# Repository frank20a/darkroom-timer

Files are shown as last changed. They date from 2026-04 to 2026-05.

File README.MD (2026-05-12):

# Darkroom f-stop timer

## Known issues:
- [X] Fix EPD power pin connected to 3.3V instead of 3V3 in KiCad schematic
- [ ] Fix SD card support (or remove it)
- [ ] Fix relays not working on PCB
- [ ] Fix issue with power supply voltage drop
    1. Test with a different power supply
    2. Add voltage measurement feedback to the microcontroller to monitor voltage levels

## Additions for future revisions:
- [ ] Add/Implement the following settings on the menu:
    - [ ] Ramp speed for light output changes
    - [ ] Save & Load templates
- [ ] Move EPD to a separate SPI bus to free up the main SPI bus for other peripherals
- [ ] Move EPD processing to a separate thread to improve responsiveness of the main application
- [ ] Add a safelight switch that bypasses everything
- [ ] Foot pedal support
- [ ] Add sensor support for light and contrast metering
- [ ] Add sensor support for color balancing

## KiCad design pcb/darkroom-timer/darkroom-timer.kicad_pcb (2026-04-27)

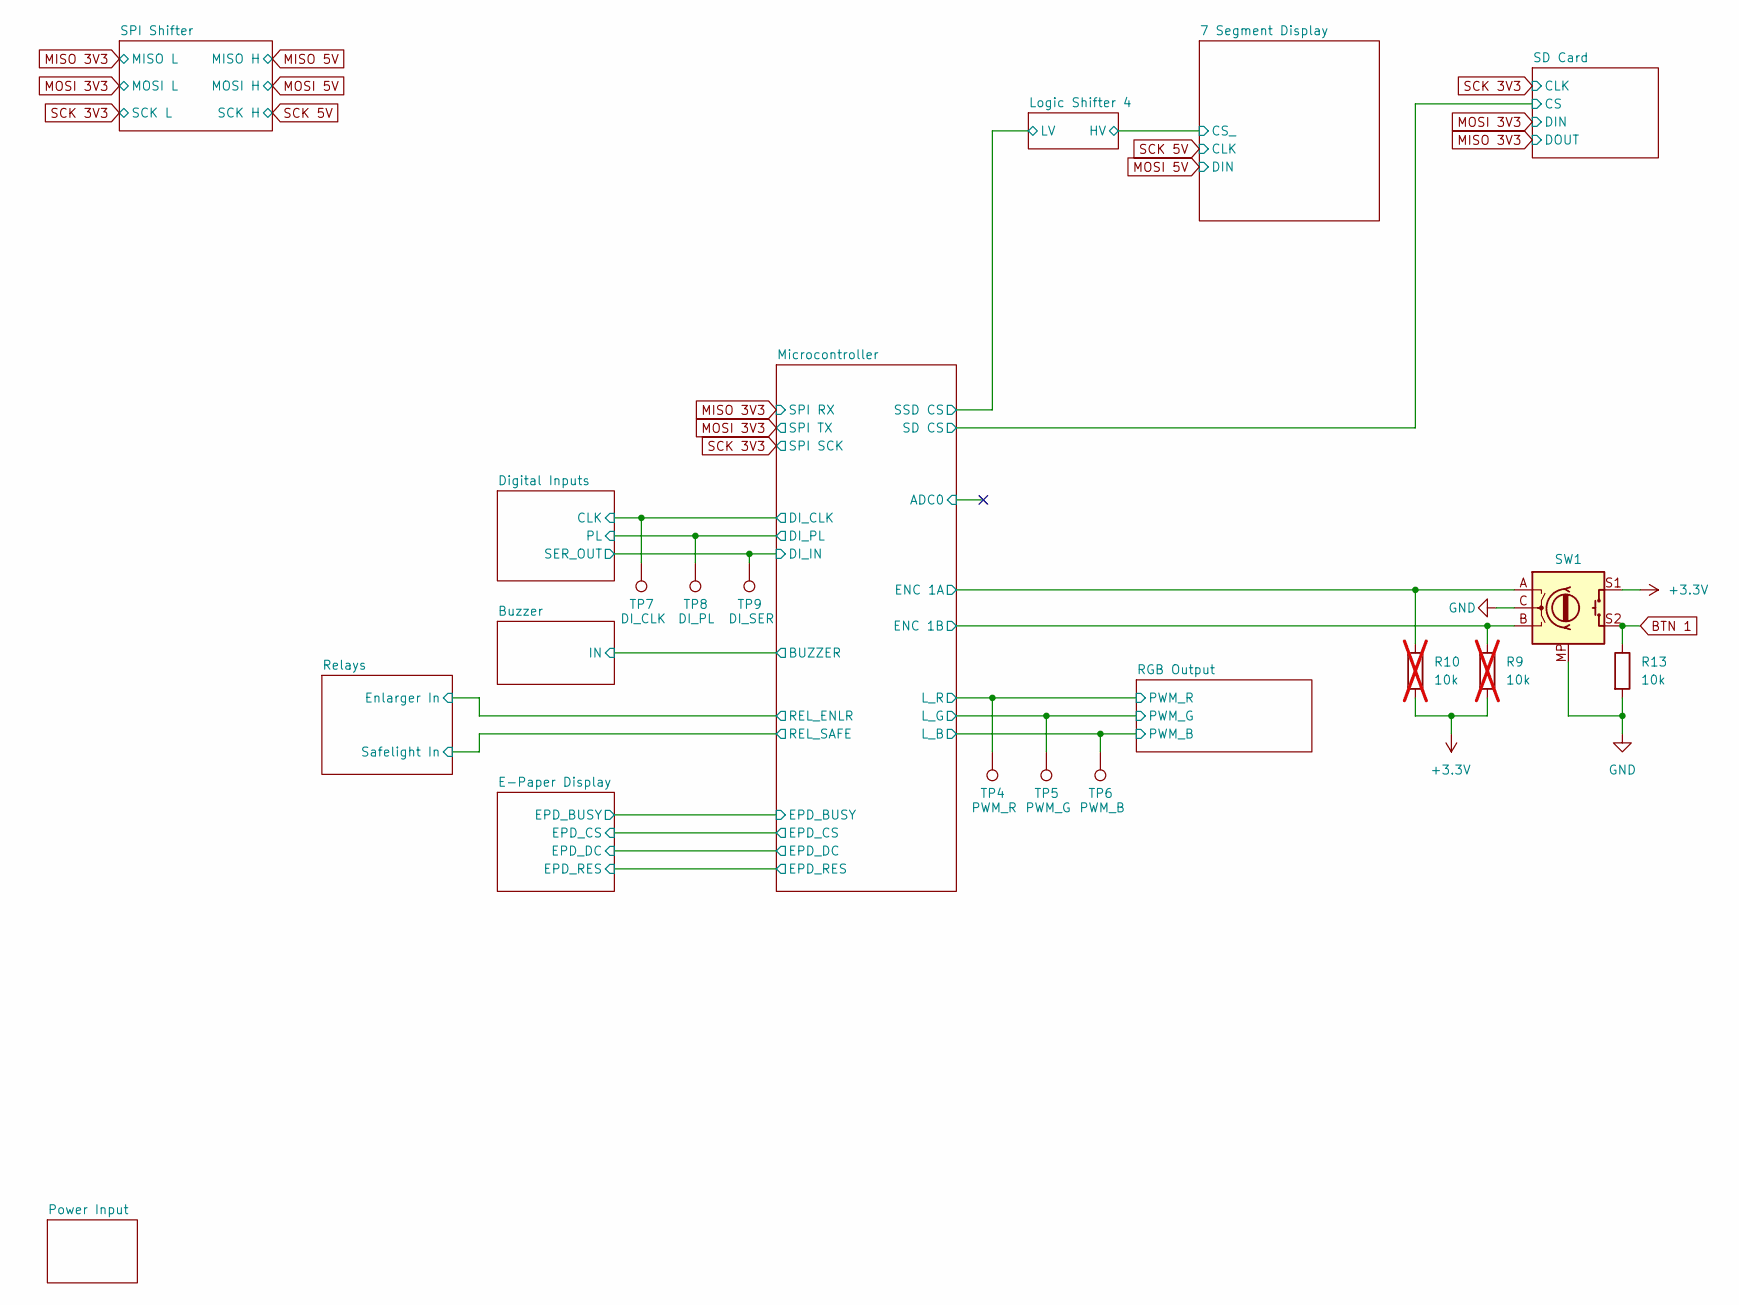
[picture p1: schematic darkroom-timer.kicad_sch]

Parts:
R9, R10: 10k; R_0805_2012Metric; not fitted
R13: 10k; R_0805_2012Metric
SW1: RotaryEncoder_Switch_MP; RotaryEncoder_Alps_EC11E-Switch_Vertical_3D
TP4: PWM_R; TestPoint_Pad_D1.5mm
TP5: PWM_G; TestPoint_Pad_D1.5mm
TP6: PWM_B; TestPoint_Pad_D1.5mm
TP7: DI_CLK; TestPoint_Pad_D1.5mm
TP8: DI_PL; TestPoint_Pad_D1.5mm
TP9: DI_SER; TestPoint_Pad_D1.5mm

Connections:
+3.3V: R9.2, R10.2, SW1.S1; also elsewhere on the board
/Digital Inputs/CLK: TP7.1; also elsewhere on the board
/Digital Inputs/PL: TP8.1; also elsewhere on the board
/Digital Inputs/SER_OUT: TP9.1; also elsewhere on the board
/Microcontroller/ENC 1A: R10.1, SW1.A; also elsewhere on the board
/Microcontroller/ENC 1B: R9.1, SW1.B; also elsewhere on the board
/Microcontroller/L_B: TP6.1; also elsewhere on the board
/Microcontroller/L_G: TP5.1; also elsewhere on the board
/Microcontroller/L_R: TP4.1; also elsewhere on the board
BTN 1: R13.1, SW1.S2; also elsewhere on the board
Earth: R13.2, SW1.C, SW1.MP; also elsewhere on the board

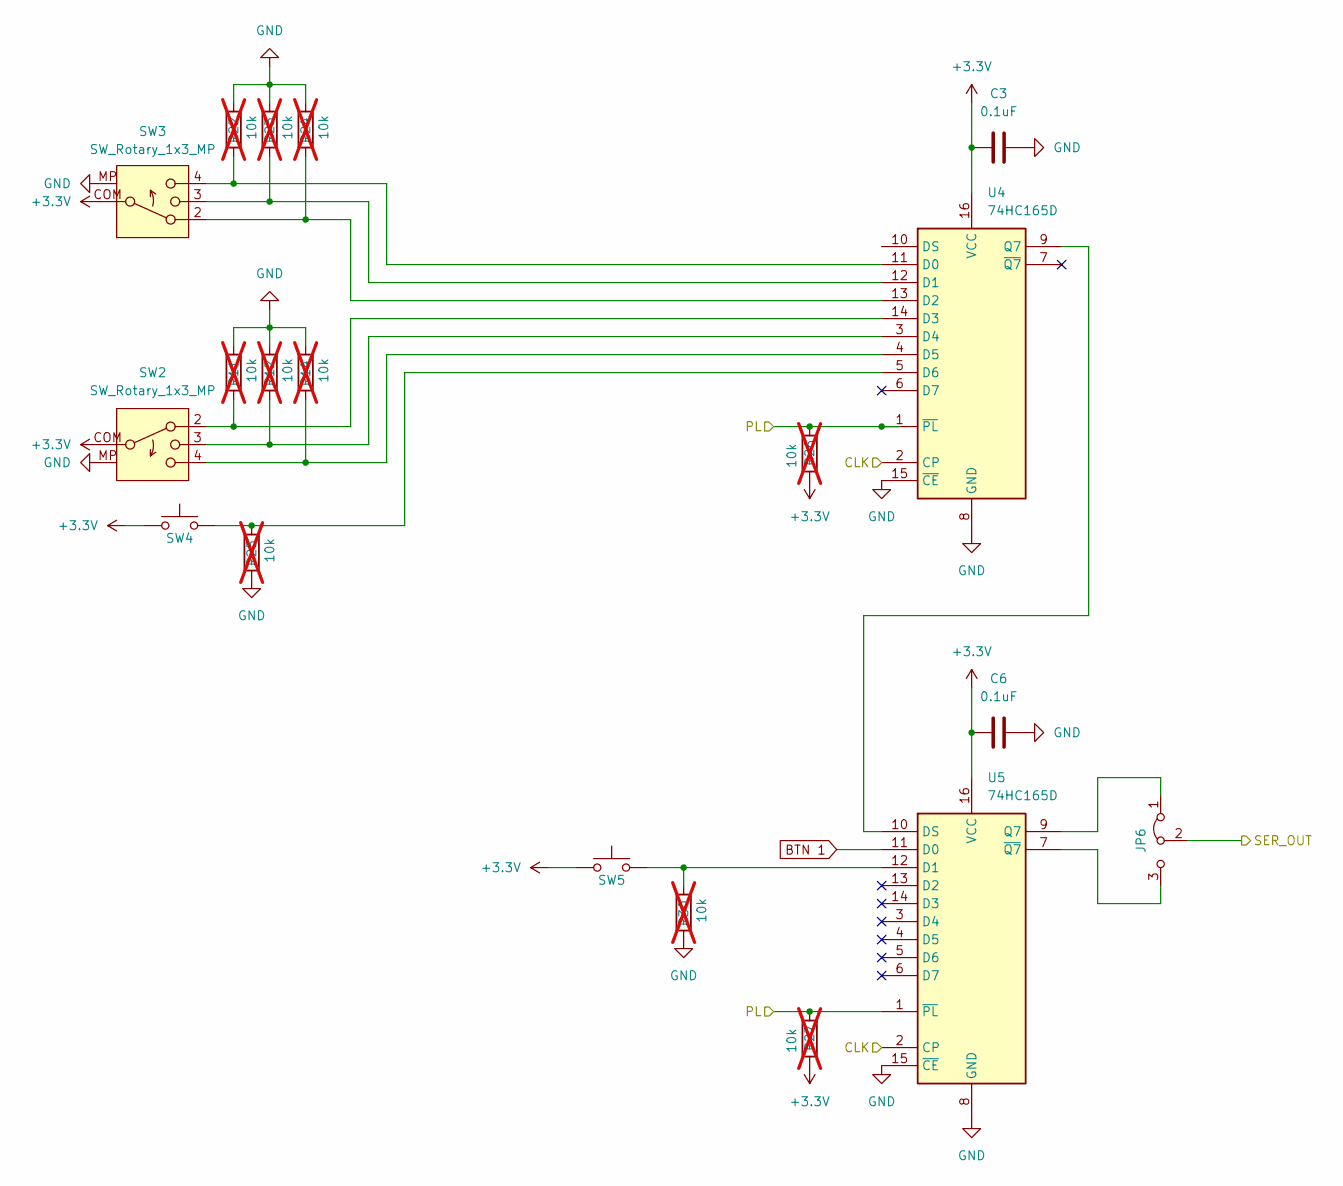
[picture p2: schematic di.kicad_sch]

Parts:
C3, C6: 0.1uF; C_0805_2012Metric
JP6: SolderJumper-3_P1.3mm_Bridged12_Pad1.0x1.5mm
R11, R12, R14, R22, R23, R24, R25, R26, R27, R30: 10k; R_0805_2012Metric; not fitted
SW2, SW3: SW_Rotary_1x3_MP; SR17A-007
SW4: Start Switch; SolderWire-0.25sqmm_1x02_P4.5mm_D0.65mm_OD2mm
SW5: Start Switch; SW_PUSH_6mm_H13mm
U4, U5: 74HC165D; SO-16_3.9x9.9mm_P1.27mm

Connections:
+3.3V: C3.1, C6.1, R26.1, R27.1, SW2.COM, SW3.COM, SW4.1, SW5.1, U4.16 (VCC), U5.16 (VCC); also elsewhere on the board
/Digital Inputs/CLK: U4.2 (CP), U5.2 (CP); also elsewhere on the board
/Digital Inputs/PL: R26.2, R27.2, U4.1 (~PL), U5.1 (~PL); also elsewhere on the board
/Digital Inputs/SER_OUT: JP6.2 (C); also elsewhere on the board
BTN 1: U5.11 (D0); also elsewhere on the board
Earth: C3.2, C6.2, R11.1, R12.1, R14.1, R22.1, R23.1, R24.1, R25.2, R30.2, SW2.MP, SW3.MP, U4.8 (GND), U4.15 (~CE), U5.8 (GND), U5.15 (~CE); also elsewhere on the board
unnamed: JP6.1 (A), U5.9 (Q7)
unnamed: JP6.3 (B), U5.7 (~Q7)
unnamed: R22.2, SW3.4, U4.11 (D0)
unnamed: R23.2, SW3.3, U4.12 (D1)
unnamed: R24.2, SW3.2, U4.13 (D2)
unnamed: R11.2, SW2.2, U4.14 (D3)
unnamed: R12.2, SW2.3, U4.3 (D4)
unnamed: R14.2, SW2.4, U4.4 (D5)
unnamed: R25.1, SW4.2, U4.5 (D6)
unnamed: U4.9 (Q7), U5.10 (DS)
unnamed: R30.1, SW5.2, U5.12 (D1)

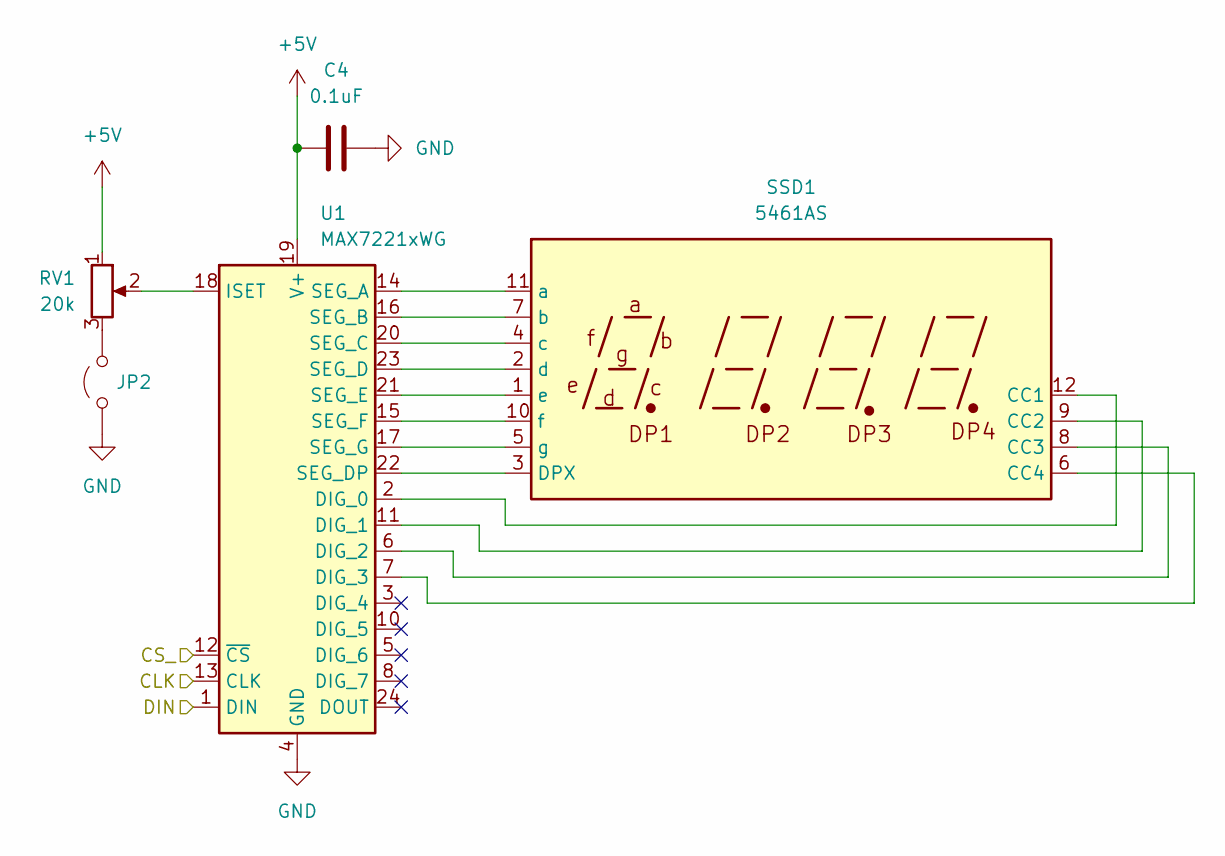
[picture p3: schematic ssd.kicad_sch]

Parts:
C4: 0.1uF; C_0805_2012Metric
JP2: SolderJumper-2_P1.3mm_Open_Pad1.0x1.5mm
RV1: 20k; RKT6V
SSD1: 5461AS; CA56-12EWA
U1: MAX7221xWG; SOIC-24W_7.5x15.4mm_P1.27mm

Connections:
+5V: C4.1, RV1.1, U1.19 (V+); also elsewhere on the board
/7 Segment Display/CS_: U1.12 (~CS); also elsewhere on the board
Earth: C4.2, JP2.1 (A), U1.4 (GND), U1.9 (GND); also elsewhere on the board
MOSI 5V: U1.1 (DIN); also elsewhere on the board
unnamed: JP2.2 (B), RV1.3
unnamed: SSD1.12 (CC1), U1.2 (DIG_0)
unnamed: SSD1.9 (CC2), U1.11 (DIG_1)
unnamed: SSD1.8 (CC3), U1.6 (DIG_2)
unnamed: SSD1.6 (CC4), U1.7 (DIG_3)
unnamed: SSD1.3 (DPX), U1.22 (SEG_DP)
unnamed: SSD1.11 (a), U1.14 (SEG_A)
unnamed: SSD1.7 (b), U1.16 (SEG_B)
unnamed: SSD1.4 (c), U1.20 (SEG_C)
unnamed: SSD1.2 (d), U1.23 (SEG_D)
unnamed: SSD1.1 (e), U1.21 (SEG_E)
unnamed: SSD1.10 (f), U1.15 (SEG_F)
unnamed: SSD1.5 (g), U1.17 (SEG_G)
unnamed: RV1.2, U1.18 (ISET)
SCK 5V: U1.13 (CLK); also elsewhere on the board

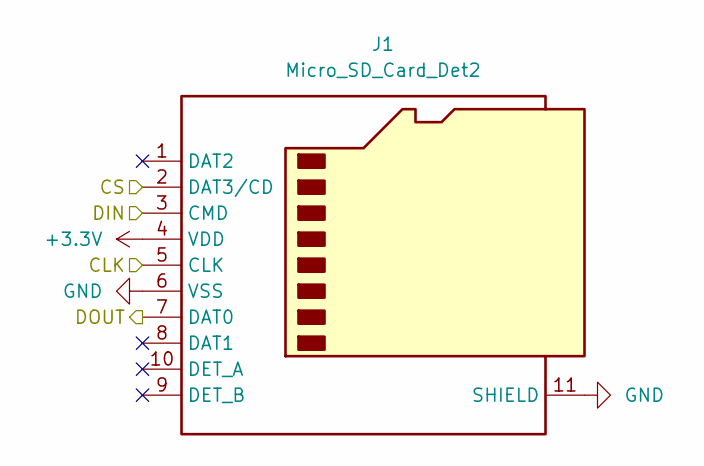
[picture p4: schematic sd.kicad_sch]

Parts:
J1: Micro_SD_Card_Det2; microSD_HC_Hirose_DM3AT-SF-PEJM5

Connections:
+3.3V: J1.4 (VDD); also elsewhere on the board
/Microcontroller/SD CS: J1.2 (DAT3/CD); also elsewhere on the board
Earth: J1.6 (VSS), J1.11 (SHIELD); also elsewhere on the board
MISO 3V3: J1.7 (DAT0); also elsewhere on the board
MOSI 3V3: J1.3 (CMD); also elsewhere on the board
SCK 3V3: J1.5 (CLK); also elsewhere on the board

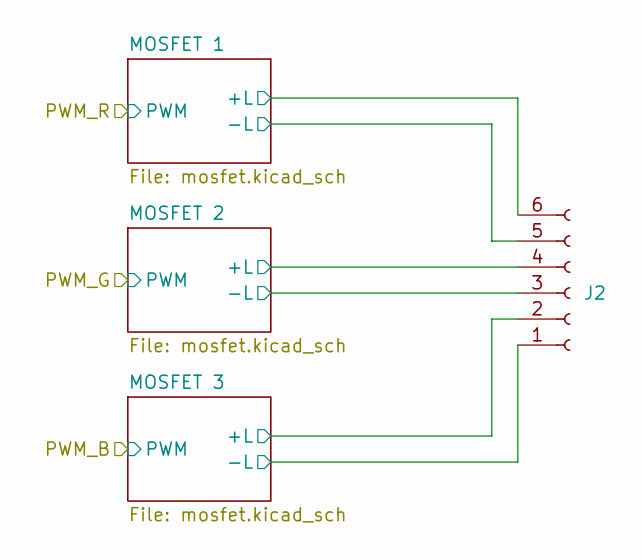
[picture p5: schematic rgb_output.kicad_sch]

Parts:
J2: Conn_01x06_Socket; PhoenixContact_MC_1,5_6-G-3.81_1x06_P3.81mm_Horizontal

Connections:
+24V: J2.2, J2.4, J2.6; also elsewhere on the board
/RGB Output/MOSFET 1/PWR_NEG: J2.5; also elsewhere on the board
/RGB Output/MOSFET 2/PWR_NEG: J2.3; also elsewhere on the board
/RGB Output/MOSFET 3/PWR_NEG: J2.1; also elsewhere on the board

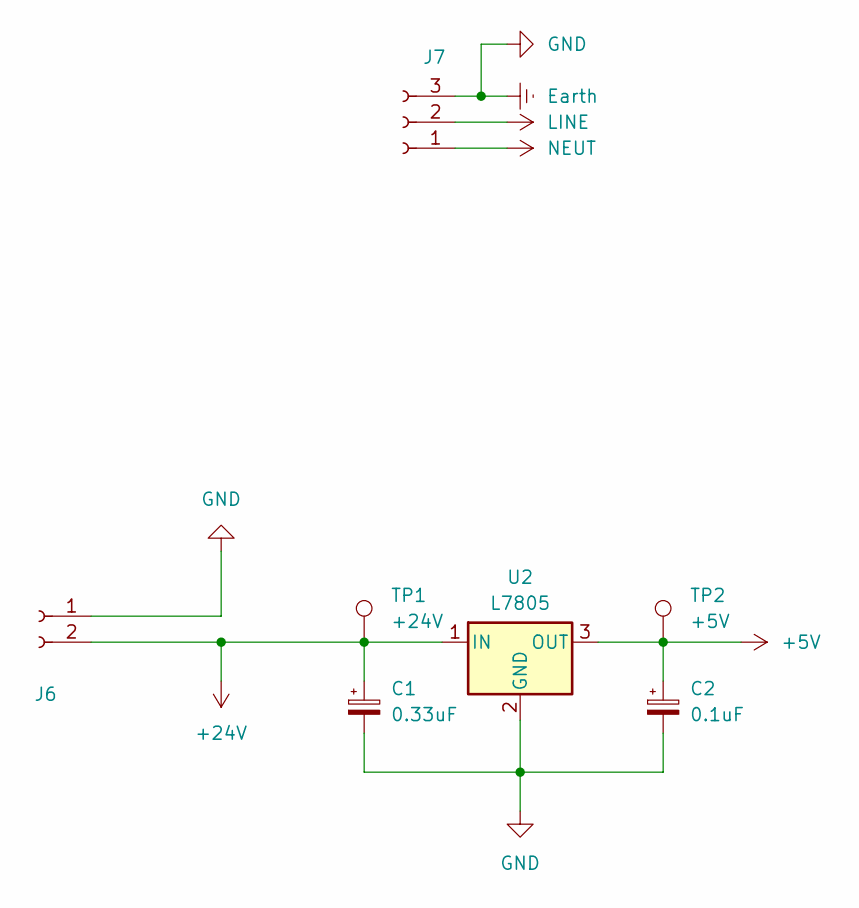
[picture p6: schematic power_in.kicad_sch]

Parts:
C1: 0.33uF; C_Radial_D4.0mm_H7.0mm_P1.50mm
C2: 0.1uF; C_Radial_D4.0mm_H7.0mm_P1.50mm
J6: Conn_01x02_Socket; PhoenixContact_MC_1,5_2-G-3.81_1x02_P3.81mm_Horizontal
J7: Conn_01x03_Socket; TerminalBlock_Phoenix_MKDS-1,5-3_1x03_P5.00mm_Horizontal
TP1: +24V; TestPoint_Pad_D1.5mm
TP2: +5V; TestPoint_Pad_D1.5mm
U2: L7805; TO-220-3_Vertical

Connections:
+5V: C2.1, TP2.1, U2.3 (OUT); also elsewhere on the board
+24V: C1.1, J6.2, TP1.1, U2.1 (IN); also elsewhere on the board
Earth: C1.2, C2.2, J6.1, J7.3, U2.2 (GND); also elsewhere on the board
LINE: J7.2; also elsewhere on the board
NEUT: J7.1; also elsewhere on the board

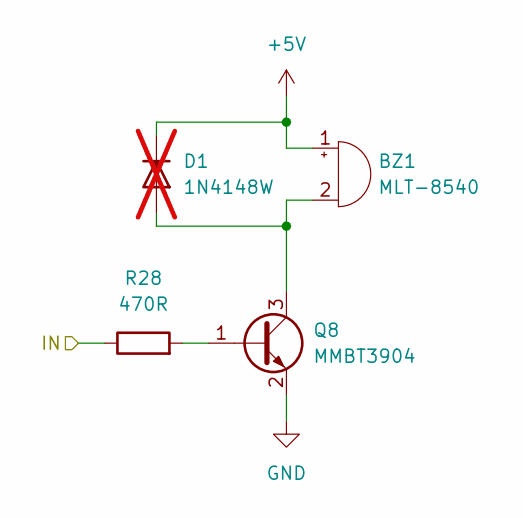
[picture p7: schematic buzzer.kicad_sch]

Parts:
BZ1: MLT-8540; Buzzer_MLT_8540
D1: 1N4148W; D_SOD-123; not fitted
Q8: MMBT3904; TSOT-23_HandSoldering
R28: 470R; R_0805_2012Metric

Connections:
+5V: BZ1.1 (+), D1.1 (K); also elsewhere on the board
/Buzzer/IN: R28.1; also elsewhere on the board
Earth: Q8.2 (E); also elsewhere on the board
unnamed: BZ1.2 (-), D1.2 (A), Q8.3 (C)
unnamed: Q8.1 (B), R28.2

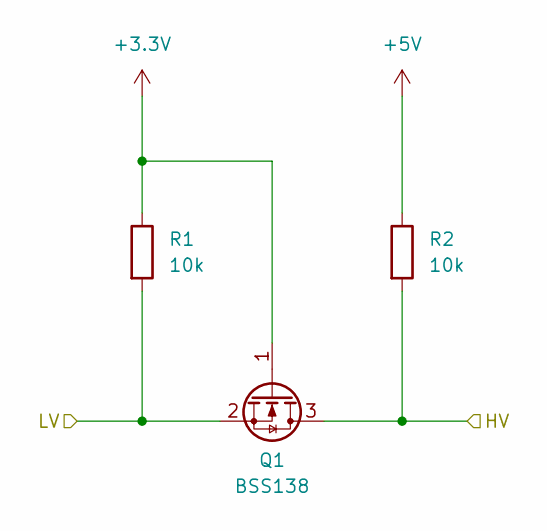
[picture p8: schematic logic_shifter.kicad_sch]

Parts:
Q1: BSS138; SOT-23
R1, R2: 10k; R_0805_2012Metric

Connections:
+3.3V: Q1.1 (G), R1.1; also elsewhere on the board
+5V: R2.1; also elsewhere on the board
MOSI 3V3: Q1.2 (S), R1.2; also elsewhere on the board
MOSI 5V: Q1.3 (D), R2.2; also elsewhere on the board

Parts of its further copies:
Q2, Q3, Q4: BSS138; SOT-23
R3, R4, R5, R6, R7, R8: 10k; R_0805_2012Metric

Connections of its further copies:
+3.3V: Q2.1 (G), Q3.1 (G), Q4.1 (G), R3.1, R5.1, R7.1; also elsewhere on the board
+5V: R4.1, R6.1, R8.1; also elsewhere on the board
/7 Segment Display/CS_: Q4.3 (D), R8.2; also elsewhere on the board
/Logic Shifter 4/LV: Q4.2 (S), R7.2; also elsewhere on the board
MISO 3V3: Q2.2 (S), R3.2; also elsewhere on the board
MISO 5V: Q2.3 (D), R4.2
SCK 3V3: Q3.2 (S), R5.2; also elsewhere on the board
SCK 5V: Q3.3 (D), R6.2; also elsewhere on the board

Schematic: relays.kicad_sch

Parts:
JP4: SolderJumper-3_P1.3mm_Bridged12_Pad1.0x1.5mm

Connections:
+5V: JP4.1 (A); also elsewhere on the board
+24V: JP4.3 (B); also elsewhere on the board
/Relays/Relay Enlarger/PWR_IN: JP4.2 (C); also elsewhere on the board

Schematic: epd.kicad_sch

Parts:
C5: 0.1uF; C_0805_2012Metric
J4: EPD Connector; PinHeader_2x04_P2.54mm_Vertical

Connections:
+3.3V: C5.1, J4.8; also elsewhere on the board
/E-Paper Display/EPD_BUSY: J4.1; also elsewhere on the board
/E-Paper Display/EPD_CS: J4.4; also elsewhere on the board
/E-Paper Display/EPD_D/C: J4.3; also elsewhere on the board
/E-Paper Display/EPD_RES: J4.2; also elsewhere on the board
Earth: C5.2, J4.7; also elsewhere on the board
MOSI 3V3: J4.5; also elsewhere on the board
SCK 3V3: J4.6; also elsewhere on the board

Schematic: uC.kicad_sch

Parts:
A1: RP Pico 2; RaspberryPi_Pico_SMD_HandSolder
JP1: SolderJumper-2_P1.3mm_Bridged_Pad1.0x1.5mm
JP3: SolderJumper-2_P1.3mm_Open_Pad1.0x1.5mm
TP3: +3V3; TestPoint_Pad_D1.5mm

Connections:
+3.3V: JP1.2 (B), JP3.1 (A), TP3.1; also elsewhere on the board
+5V: A1.40 (VBUS); also elsewhere on the board
/Buzzer/IN: A1.29 (GPIO22); also elsewhere on the board
/Digital Inputs/CLK: A1.12 (GPIO9); also elsewhere on the board
/Digital Inputs/PL: A1.14 (GPIO10); also elsewhere on the board
/Digital Inputs/SER_OUT: A1.15 (GPIO11); also elsewhere on the board
/E-Paper Display/EPD_BUSY: A1.16 (GPIO12); also elsewhere on the board
/E-Paper Display/EPD_CS: A1.17 (GPIO13); also elsewhere on the board
/E-Paper Display/EPD_D/C: A1.19 (GPIO14); also elsewhere on the board
/E-Paper Display/EPD_RES: A1.20 (GPIO15); also elsewhere on the board
/Logic Shifter 4/LV: A1.26 (GPIO20); also elsewhere on the board
/Microcontroller/ADC0: A1.31 (GPIO26_ADC0)
/Microcontroller/ENC 1A: A1.4 (GPIO2); also elsewhere on the board
/Microcontroller/ENC 1B: A1.5 (GPIO3); also elsewhere on the board
/Microcontroller/L_B: A1.9 (GPIO6); also elsewhere on the board
/Microcontroller/L_G: A1.7 (GPIO5); also elsewhere on the board
/Microcontroller/L_R: A1.6 (GPIO4); also elsewhere on the board
/Microcontroller/REL_ENLR: A1.11 (GPIO8); also elsewhere on the board
/Microcontroller/REL_SAFE: A1.10 (GPIO7); also elsewhere on the board
/Microcontroller/SD CS: A1.27 (GPIO21); also elsewhere on the board
Earth: A1.3 (GND), A1.8 (GND), A1.13 (GND), A1.18 (GND), A1.23 (GND), A1.28 (GND), A1.33 (AGND), A1.38 (GND); also elsewhere on the board
MISO 3V3: A1.21 (GPIO16); also elsewhere on the board
MOSI 3V3: A1.25 (GPIO19); also elsewhere on the board
unnamed: A1.36 (3V3), JP1.1 (A)
unnamed: A1.37 (3V3_EN), JP3.2 (B)
SCK 3V3: A1.24 (GPIO18); also elsewhere on the board

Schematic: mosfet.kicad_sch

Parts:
Q5: IRLB8721PBF; TO-220-3_Vertical
R15: 10k; R_0805_2012Metric
R16: 220R; R_0805_2012Metric

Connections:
/Microcontroller/L_R: R15.1, R16.1; also elsewhere on the board
/RGB Output/MOSFET 1/PWR_NEG: Q5.2 (D); also elsewhere on the board
Earth: Q5.3 (S), R15.2; also elsewhere on the board
unnamed: Q5.1 (G), R16.2

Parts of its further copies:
Q6, Q7: IRLB8721PBF; TO-220-3_Vertical
R17, R19: 10k; R_0805_2012Metric
R18, R20: 220R; R_0805_2012Metric

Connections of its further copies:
/Microcontroller/L_B: R19.1, R20.1; also elsewhere on the board
/Microcontroller/L_G: R17.1, R18.1; also elsewhere on the board
/RGB Output/MOSFET 2/PWR_NEG: Q6.2 (D); also elsewhere on the board
/RGB Output/MOSFET 3/PWR_NEG: Q7.2 (D); also elsewhere on the board
Earth: Q6.3 (S), Q7.3 (S), R17.2, R19.2; also elsewhere on the board
unnamed: Q6.1 (G), R18.2
unnamed: Q7.1 (G), R20.2

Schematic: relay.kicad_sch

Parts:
J3: Conn_01x02_Socket; TerminalBlock_Phoenix_MKDS-1,5-2_1x02_P5.00mm_Horizontal
K1: Relay_DPDT; Relay_DPDT_Panasonic_JW2_Custom
R21: 1k; R_0805_2012Metric
U3: PC817; DIP-4_W7.62mm

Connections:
/Microcontroller/REL_ENLR: U3.1; also elsewhere on the board
/Relays/Relay Enlarger/L_OUT: J3.1, K1.21
/Relays/Relay Enlarger/N_OUT: J3.2, K1.11
/Relays/Relay Enlarger/PWR_IN: R21.1; also elsewhere on the board
Earth: K1.A2, U3.2; also elsewhere on the board
LINE: K1.24; also elsewhere on the board
NEUT: K1.14; also elsewhere on the board
unnamed: K1.A1, U3.3
unnamed: R21.2, U3.4

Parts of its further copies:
J5: Conn_01x02_Socket; TerminalBlock_Phoenix_MKDS-1,5-2_1x02_P5.00mm_Horizontal
K2: Relay_DPDT; Relay_DPDT_Panasonic_JW2_Custom
R29: 1k; R_0805_2012Metric
U6: PC817; DIP-4_W7.62mm

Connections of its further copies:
/Microcontroller/REL_SAFE: U6.1; also elsewhere on the board
/Relays/Relay Enlarger/PWR_IN: R29.1; also elsewhere on the board
/Relays/Relay Safelight/L_OUT: J5.1, K2.21
/Relays/Relay Safelight/N_OUT: J5.2, K2.11
Earth: K2.A2, U6.2; also elsewhere on the board
LINE: K2.24; also elsewhere on the board
NEUT: K2.14; also elsewhere on the board
unnamed: K2.A1, U6.3
unnamed: R29.2, U6.4

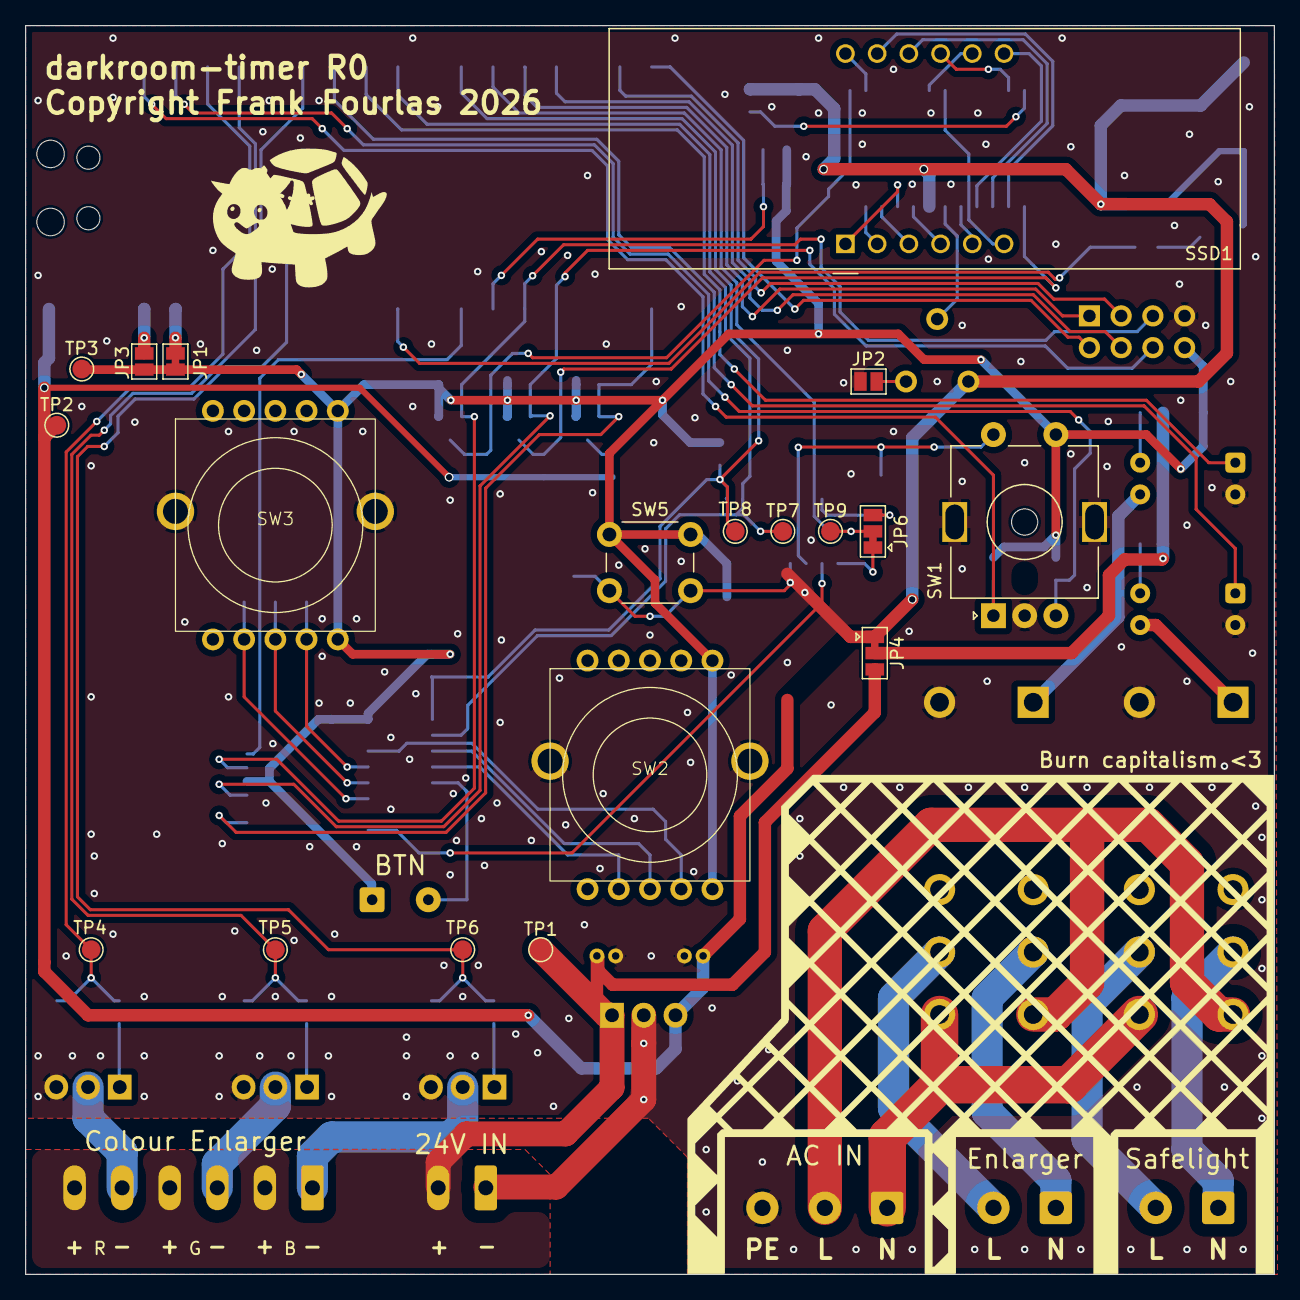
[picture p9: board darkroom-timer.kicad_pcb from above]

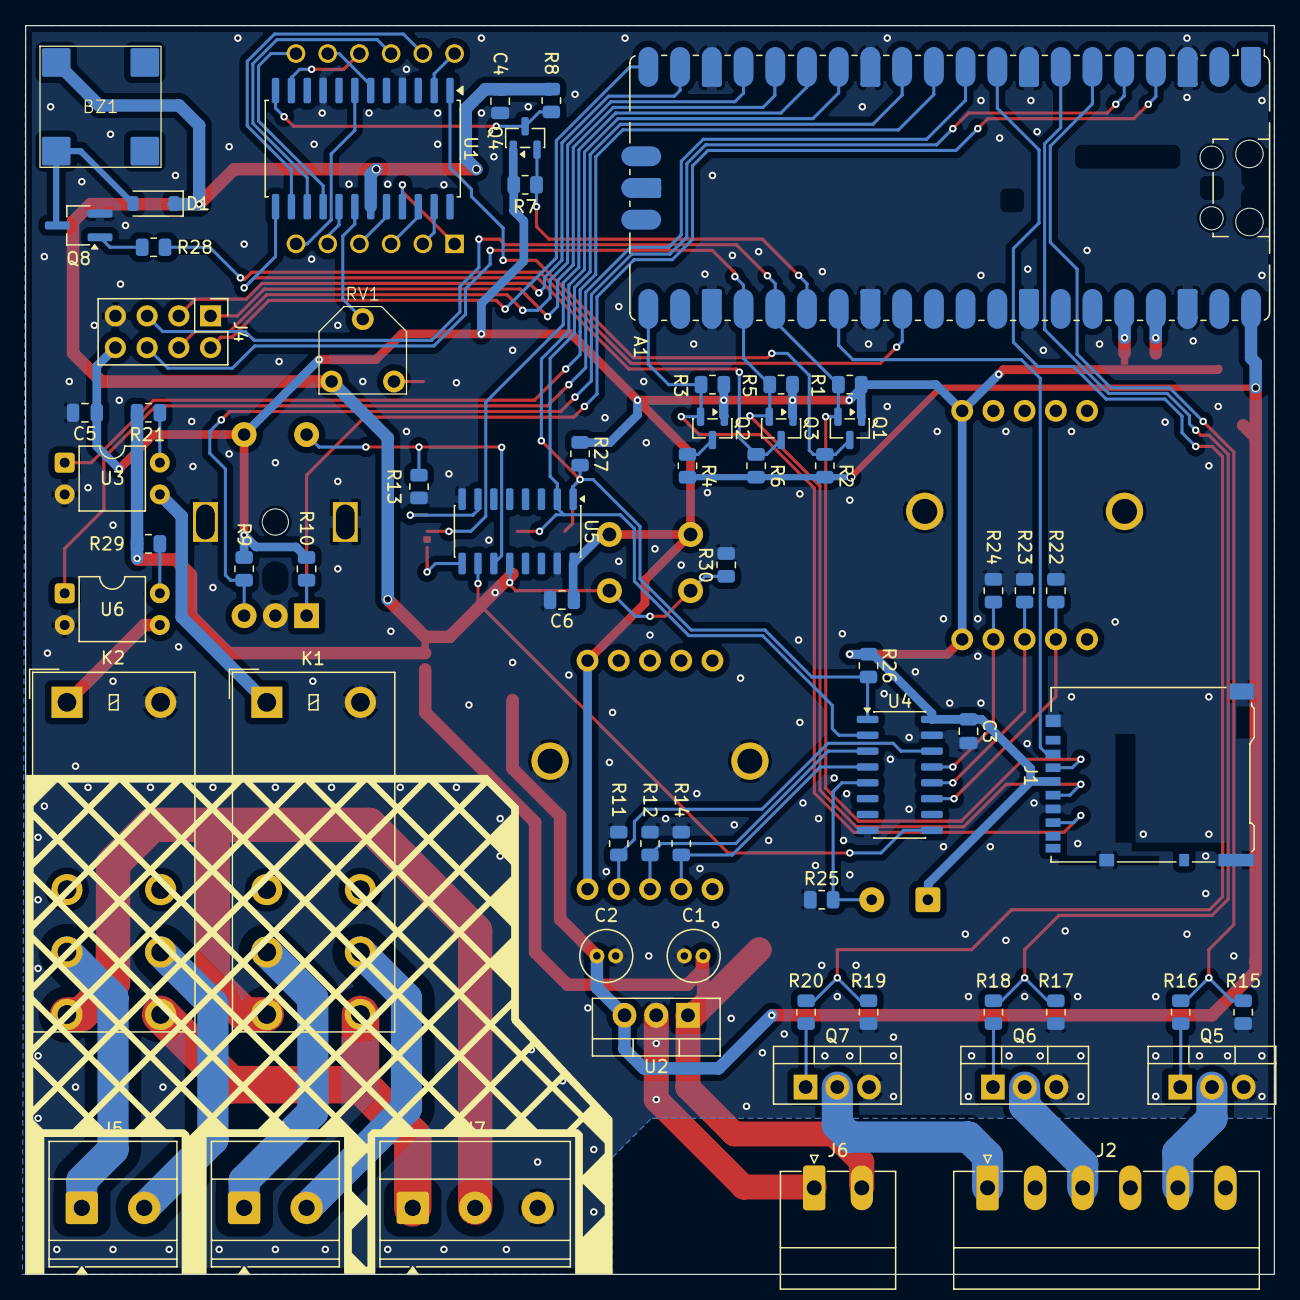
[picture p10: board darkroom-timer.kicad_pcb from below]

Board: 2 copper layers, 100.0 x 100.0 mm, 83 parts (63 on the bottom side), 75 nets.

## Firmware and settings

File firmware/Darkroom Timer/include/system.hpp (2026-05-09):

#pragma once


#include "inputs.hpp"
#include "outputs.hpp"


#define FSTOP_NUM_SELECTIONS 6
#define TIMER_NUM_SELECTIONS 6
#define DEFAULT_FSTOP_STEP_INDEX 4
#define DEFAULT_TIMER_STEP_INDEX 2


enum class LightSourceType {
    NONE = 0,
    LAMP,
    SINGLE_ANALOG,
    TRIPLE_ANALOG
};

enum class AnalogOutputFunction {
    LINEAR = 0,
    EXPONENTIAL,
    POLY_2,
    POLY_3
};


struct SystemSettings {
    LightSourceType light_source = LightSourceType::NONE;
    uint8_t seven_segment_brightness = 0x0F; // 0x00 to 0x0F
    AnalogOutputFunction analog_output_function = AnalogOutputFunction::LINEAR;
    double analog_output_coeffs[3][4] = {0}; // [light_source][coeff_index]
    int analog_output_range[3][2] = {0}; // [light_source][min/max]
    double analog_output_voltage_limit = 0;
    double analog_input_voltage = 0;
    unsigned int buzzer_frequency = 3000; // In Hz
    unsigned int magic_number = 0xDEADBEEF; // For validating settings data
};

struct TimerTemplate {
    char title[20] = "Untitled Timer";
    
    // Light source setpoints
    int color_setpoints[3] = {0};
    bool color_enabled[3] = {true, true, true};

    // Test-strip related setpoints

    // Timer related setpoints
    static const uint8_t f_steps[FSTOP_NUM_SELECTIONS];
    static const float t_steps[TIMER_NUM_SELECTIONS];
    uint8_t f_step_index = DEFAULT_FSTOP_STEP_INDEX, t_step_index = DEFAULT_TIMER_STEP_INDEX;

};


struct SystemState {
    InputData inputs;
    OutputData outputs;
    TimerTemplate timer_setpoint;
    SystemSettings settings;
};

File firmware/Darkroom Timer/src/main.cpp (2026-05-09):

#include "application.hpp"


Application app;


/* ======================== Function definitions =========================== */
void setup() {
    // Initialize Serial
    Serial.begin(115200);
    delay(200);

    // Initialize application
    if(!app.begin()) {
        Serial.println("Failed to initialize application.");
        while(1);
    }
}


void loop() {
    app.mainloop_step();
}

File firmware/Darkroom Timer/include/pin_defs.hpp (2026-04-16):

#define MOSI_PIN 19
#define MISO_PIN 16
#define SCK_PIN 18

#define EPD_CS_PIN 13
#define EPD_DC_PIN 14
#define EPD_RES_PIN 15
#define EPD_BUSY_PIN 12

#define DI_IN_PIN 11
#define DI_PL_PIN 10
#define DI_CLK_PIN 9

#define REL_ENLR_PIN 8
#define REL_SAFE_PIN 7

#define LIGHT_OUT_R_PIN 4
#define LIGHT_OUT_G_PIN 5
#define LIGHT_OUT_B_PIN 6

#define BUZZER_PIN 22

#define ENC1_A_PIN 2
#define ENC1_B_PIN 3     // Assume that it is ENC1_A_PIN + 1

#define SSD_CS_PIN 20
#define SD_CS_PIN 21

// #define POT1_PIN A0

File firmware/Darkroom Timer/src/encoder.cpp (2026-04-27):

#include "encoder.hpp"


Encoder* Encoder::instance = nullptr;

Encoder::Encoder(uint pinA) : pinA(pinA), encoder_value(0) {
    sm = pio_claim_unused_sm(pio, true);                                        // Find first free state machine and claim it

    Encoder::instance = this;                                                   // Register this instance in the static instances array so we can refer to it from the static IRQ handler
}

bool Encoder::begin() {
    // This PIO program uses a fixed .origin 0 jump table, so it must be loaded at offset 0.
    if (!pio_can_add_program_at_offset(pio, &pio_rotary_encoder_program, 0)) {
        Serial.println("Encoder PIO error: program offset 0 unavailable");
        return false;
    }

    program_offset = pio_add_program_at_offset(pio, &pio_rotary_encoder_program, 0);
    pio_sm_config c = pio_rotary_encoder_program_get_default_config(program_offset);    // Get default state machine configuration struct and set up as required
    
    sm_config_set_in_pins(&c, pinA);                                           // Set the input pin for the state machine to the first encoder pin
    sm_config_set_in_shift(&c, false, false, 0);                               // Required for this ISR jump-table decoder
    sm_config_set_out_shift(&c, true, false, 0);
    pio_gpio_init(pio, pinA);                                                  // Init GPIO
    pio_gpio_init(pio, pinA + 1);
    gpio_pull_up(pinA);
    gpio_pull_up(pinA + 1);
    pio_sm_set_consecutive_pindirs(pio, sm, pinA, 2, false);                   // Set the 2 pins (A and B) as inputs
    sm_config_set_clkdiv(&c, 1250.0f);                                          // Set the speed to 100kHz
    pio_sm_init(pio, sm, program_offset + 16, &c);
    pio_sm_set_enabled(pio, sm, true);                                          // Start the state machine 
    irq_set_exclusive_handler(PIO0_IRQ_0, Encoder::encoder_pio_irq_handler);    // Set the IRQ handler for the PIO interrupt
    irq_set_enabled(PIO0_IRQ_0, true);                                          // Enable the PIO interrupt
    pio_set_irq0_source_enabled(pio, pis_interrupt0, true);                     // Enable the state machine's IRQ output to cause an interrupt on the processor
    pio_set_irq0_source_enabled(pio, pis_interrupt1, true);
    
    return true;
}

void Encoder::encoder_pio_irq_handler() {
    if (Encoder::instance == nullptr) {
        return;
    }

    uint32_t irq_flags = pio0->irq & 0x3u;

    if (irq_flags & 0x1u) {  // IRQ 0
        Encoder::instance->encoder_value--;
    }

    if (irq_flags & 0x2u) {  // IRQ 1
        Encoder::instance->encoder_value++;
    }

    if (irq_flags != 0) {
        pio0->irq = irq_flags;  // Write-1-to-clear
    }
}

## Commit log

2026-03-09 PCB Schematic
    [darkroom-timer.kicad_pcb, darkroom-timer.kicad_sch, di.kicad_sch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]
2026-03-15 PCB Ready
    [buzzer.kicad_sch, darkroom-timer.kicad_pcb, darkroom-timer.kicad_sch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]
2026-03-17 Correct Connectors
    [darkroom-timer.kicad_pcb, power_in.kicad_sch, rgb_output.kicad_sch]
2026-03-23 EPD Tests
    [epd.kicad_sch]
2026-03-31 Encoder + Digital Inputs
2026-04-16 Shift Registers + Encoder + 7SD
2026-04-19 Final PCB R0 design
    [darkroom-timer.kicad_pcb, di.kicad_sch, epd.kicad_sch]
2026-04-27 Settings page Major work + changes
    [darkroom-timer.kicad_pcb, epd.kicad_sch]
2026-05-09 Timer & Light Control Pages Done
2026-05-12 Fix inrush current issue
    [application.cpp, application.hpp, pages.cpp]

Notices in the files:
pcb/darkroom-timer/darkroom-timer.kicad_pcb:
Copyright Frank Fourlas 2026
